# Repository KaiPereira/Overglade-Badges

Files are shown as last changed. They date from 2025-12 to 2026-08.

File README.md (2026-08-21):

# Overglade Hackathon Badges

These are zero-power hackathon badges I designed for the overglade hackathon in singapore! They're powered by the RP2040 and have passive NFC and an onboard e-ink driver! 





## Custom Features
- Passive NFC tap for whatever your heart desires
- E-ink support so that you don't need any battery
- 20 GPIO's broken out onto header pins for programming
- Active NFC mode if you want to do some more complicated stuff
- Zero power, the board needs no power for it's core features
- RP2040 SoC with 4MB flash memory
- Cool PCB and exposed copper art

## PCB Design

The PCB is a simple, 2 layer board with ground fills on each layer. I also CAD'ed the shapes and art of the board to make sure everything was perfectly symmetrical!





## Programming and Setup

The board is really easy to setup! Just plug it into your computer via USB-C, drop in the [Pi Pico micropython bootloader](https://micropython.org/download/RPI_PICO/) and then upload the [firmware](/firmware) using Thonny to the devboard! 

You can modify the `config.json` to add your own personal details, and change the images by replacing the bitmaps (I like to use [Magick](https://imagemagick.org/#gsc.tab=0) for this)!

## Ordering the PCB's

The boards are really easy to get manufactured if you'd like to have some of your own! They're much cheaper to order in bulk, at about less than $5/board and another $5 for the e-ink, but getting at MOQ will cost about $100 for 5 with PCBA (hand soldering is probably significantly cheaper though). 

I used JLC to PCBA my boards, you can just drag and drop the `gerbers.zip`, and then use the JLC BOM and designators/CPL all in the [productions folder](/PCB/production). Some of the part orientations might be off, so make sure you correct those! 

## Contributions

These were badges for the [overglade hackathon](https://overglade.hackclub.com/) in singapore, a HackClub event for highschoolers! 

Thanks to the whole overglade team for their hard work in putting the event together, and thanks to @nimitvijayvargee and @mpkendall for helping with firmware - @joysudo, @froppii and @mynameisashllee for helping with the art!

Keep on hacking o7

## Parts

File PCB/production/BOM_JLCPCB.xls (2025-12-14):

JLCPCB BOM Tool - BOM Matching
BOM name：bom-JLCPCB Assembly Order.xlsx |  |  | Download Time：2025-12-15 06:33:50 |  |  |  | * Our matching results are updated in real-time, but stock and prices may change. If it's been over 24 hours, please re-match before placing your order.
PCB Assembled Qty：5 |  |  | Est. Total Price：15.1631
Your BOM |  |  |  |  | Matched Parts |  |  |  |  |  |  | Order Information
Top Designator | Bottom Designator | Comment | Footprint | JLCPCB Part # | Matches | Part # | Manufacturer | Footprint | Description | Category | Warning | JLCPCB Part # | Product link | Lib Type | Qty | Source | Total Price ($)
C1,C2 |  | 10uF | 0805 |  | Select by System | CL21A106KAYNNNE | Samsung Electro-Mechanics | 0805 | 10uF 25V X5R ±10% 0805 Multilayer Ceramic Capacitors MLCC - SMD/SMT ROHS | Multilayer Ceramic Capacitors MLCC - SMD/SMT |  | C15850 | https://jlcpcb.com/partdetail/16532-CL21A106KAYNNNE/C15850 | Basic | 10 | 10 JLCPCB | 0.098
C10,C12,C13,C16,C29,C4,C5,C6,C7,C8,C9 |  | 0.1uF | 0402 |  | Unconfirmed | CL05B104KO5NNNC | Samsung Electro-Mechanics | 0402 | 100nF 16V X7R ±10% 0402 Multilayer Ceramic Capacitors MLCC - SMD/SMT ROHS | Multilayer Ceramic Capacitors MLCC - SMD/SMT | 1.The comment (CL05B104KO5NNNC) of this part does not match the one (0.1uF) provided in your BOM. Please confirm; | C1525 | https://jlcpcb.com/partdetail/1877-CL05B104KO5NNNC/C1525 | Basic | 55 | 55 JLCPCB | 0.066
C11,C17,C18,C19,C20,C21,C22,C23,C24,C25,C26,C3 |  | 1uF | 0402 |  | Select by System | CL05A105KA5NQNC | Samsung Electro-Mechanics | 0402 | 1uF 25V X5R ±10% 0402 Multilayer Ceramic Capacitors MLCC - SMD/SMT ROHS | Multilayer Ceramic Capacitors MLCC - SMD/SMT |  | C52923 | https://jlcpcb.com/partdetail/53938-CL05A105KA5NQNC/C52923 | Basic | 60 | 60 JLCPCB | 0.174
C14,C15,C30 |  | 33pF | 0402 |  | Select by System | 0402CG330J500NT | FH (Guangdong Fenghua Advanced Tech) | 0402 | 33pF 50V C0G ±5% 0402 Multilayer Ceramic Capacitors MLCC - SMD/SMT ROHS | Multilayer Ceramic Capacitors MLCC - SMD/SMT |  | C1562 | https://jlcpcb.com/partdetail/1914-0402CG330J500NT/C1562 | Basic | 15 | 15 JLCPCB | 0.015
C27,C28 |  | 4.7uF | 0603 |  | Select by System | CL10A475KO8NNNC | Samsung Electro-Mechanics | 0603 | 16V 4.7uF X5R ±10% 0603 Multilayer Ceramic Capacitors MLCC - SMD/SMT ROHS | Multilayer Ceramic Capacitors MLCC - SMD/SMT |  | C19666 | https://jlcpcb.com/partdetail/20375-CL10A475KO8NNNC/C19666 | Basic | 10 | 10 JLCPCB | 0.092
D1 |  | KT-0805G | 0805 |  | Select by System | KT-0805G | Hubei KENTO Elec | 0805 | -40℃~+85℃ 100mW 120° 2.6V~3.1V 430mcd 513nm~528nm 525nm 5mA Emerald Green 0805 LED Indication - Discrete ROHS | LED Indication - Discrete |  | C2297 | https://jlcpcb.com/partdetail/Hubei_KENTOElec-KT0805G/C2297 | Basic | 5 | 5 JLCPCB | 0.054
D2,D3,D4 |  | MBR0530 | D_SOD-123 |  | Select by System | MBR0530 | TWGMC | SOD-123 | 130uA 30V 5.5A 500mA 500mV@500mA Independent SOD-123 Schottky Diodes ROHS | Schottky Diodes |  | C5204746 | https://jlcpcb.com/partdetail/TWGMC-MBR0530/C5204746 | Extended | 23 | 23 JLCPCB | 0.4278
J1 |  | USB_C_Receptacle_USB2.0_16P | USB_C_Receptacle_HRO_TYPE-C-31-M-12 |  | Select by Customer | TYPE-C-31-M-12 | Korean Hroparts Elec | SMD | 1 16P 5A Female Type-C SMD USB Connectors ROHS | USB Connectors |  | C165948 | https://jlcpcb.com/partdetail/Korean_HropartsElec-TYPE_C_31_M12/C165948 | Extended | 5 | 5 JLCPCB | 0.847
L2 |  | 68uH | L_Changjiang_FNR6028S |  | Select by Customer | FNR6028S680MT | cjiang (Changjiang Microelectronics Tech) | SMD,6x6mm | 468mΩ 68uH 950mA 950mA Magnetic Shielded Inductor ±20% SMD,6x6mm Power Inductors ROHS | Power Inductors |  | C168045 | https://jlcpcb.com/partdetail/179428-FNR6028S680MT/C168045 | Extended | 6 | 6 JLCPCB | 0.3978
Q2 |  | IRLML2060 | SOT-23 |  | Unconfirmed | IRLML2060TRPBF | TECH PUBLIC | SOT-23 | 105mΩ@10V 19.5pF 247pF 2V 34pF 350mW 3A 60V 6nC@4.5V SOT-23 MOSFETs ROHS | MOSFETs | 1.The comment (IRLML2060TRPBF) of this part does not match the one (IRLML2060) provided in your BOM. Please confirm; | C5122027 | https://jlcpcb.com/partdetail/TECHPUBLIC-IRLML2060TRPBF/C5122027 | Extended | 9 | 9 JLCPCB | 0.5607
R1,R2 |  | 5.1K | 0402 |  | Unconfirmed | 0402WGF5101TCE | UNI-ROYAL(Uniroyal Elec) | 0402 | -55℃~+155℃ 5.1kΩ 50V 62.5mW Thick Film Resistor ±1% ±100ppm/℃ 0402 Chip Resistor - Surface Mount ROHS | Chip Resistor - Surface Mount | 1.The comment (0402WGF5101TCE) of this part does not match the one (5.1K) provided in your BOM. Please confirm; | C25905 | https://jlcpcb.com/partdetail/26648-0402WGF5101TCE/C25905 | Basic | 10 | 10 JLCPCB | 0.005
R3,R4 |  | 22 | 0402 |  | Unconfirmed | 0402WGF220JTCE | UNI-ROYAL(Uniroyal Elec) | 0402 | -55℃~+155℃ 22Ω 50V 62.5mW Thick Film Resistor ±1% ±100ppm/℃ 0402 Chip Resistor - Surface Mount ROHS | Chip Resistor - Surface Mount | 1.The comment (0402WGF220JTCE) of this part does not match the one (22) provided in your BOM. Please confirm; | C25092 | https://jlcpcb.com/partdetail/25835-0402WGF220JTCE/C25092 | Basic | 10 | 10 JLCPCB | 0.006
R6,R9 |  | 1K | 0402 |  | Unconfirmed | 0402WGF1001TCE | UNI-ROYAL(Uniroyal Elec) | 0402 | -55℃~+155℃ 1kΩ 50V 62.5mW Thick Film Resistor ±1% ±100ppm/℃ 0402 Chip Resistor - Surface Mount ROHS | Chip Resistor - Surface Mount | 1.The comment (0402WGF1001TCE) of this part does not match the one (1K) provided in your BOM. Please confirm; | C11702 | https://jlcpcb.com/partdetail/12256-0402WGF1001TCE/C11702 | Basic | 10 | 10 JLCPCB | 0.006
R7 |  | 220 | 0402 |  | Unconfirmed | 0402WGF2200TCE | UNI-ROYAL(Uniroyal Elec) | 0402 | -55℃~+155℃ 220Ω 50V 62.5mW Thick Film Resistor ±1% ±100ppm/℃ 0402 Chip Resistor - Surface Mount ROHS | Chip Resistor - Surface Mount | 1.The comment (0402WGF2200TCE) of this part does not match the one (220) provided in your BOM. Please confirm; | C25091 | https://jlcpcb.com/partdetail/25834-0402WGF2200TCE/C25091 | Basic | 5 | 5 JLCPCB | 0.003
R10,R11,R13,R14,R5,R8 |  | 10K | 0402 |  | Unconfirmed | 0402WGF1002TCE | UNI-ROYAL(Uniroyal Elec) | 0402 | -55℃~+155℃ 10kΩ 50V 62.5mW Thick Film Resistor ±1% ±100ppm/℃ 0402 Chip Resistor - Surface Mount ROHS | Chip Resistor - Surface Mount | 1.The comment (0402WGF1002TCE) of this part does not match the one (10K) provided in your BOM. Please confirm; | C25744 | https://jlcpcb.com/partdetail/26487-0402WGF1002TCE/C25744 | Basic | 30 | 30 JLCPCB | 0.015
R12 |  | 0.47 | 0402 |  | Unconfirmed | 0402WGF470LTCE | UNI-ROYAL(Uniroyal Elec) | 0402 | -55℃~+155℃ 470mΩ 50V 62.5mW Thick Film Resistor ±1% ±800ppm/℃ 0402 Chip Resistor - Surface Mount ROHS | Chip Resistor - Surface Mount | 1.The comment (0402WGF470LTCE) of this part does not match the one (0.47) provided in your BOM. Please confirm; | C423162 | https://jlcpcb.com/partdetail/416112-0402WGF470LTCE/C423162 | Extended | 20 | 20 JLCPCB | 0.078
SW1,SW2,SW3 |  | TSA016A2526B | SW_Push_SPST_TSA016 |  | Select by System | TSA016A2526B | BZCN | SMD,4.2x3.4mm | 12V 2.5mm 2.6N 3.35mm 4.2mm 50mA Oval Button Surface Mount,Vertical White SMD,4.2x3.4mm Tactile Switches ROHS | Tactile Switches |  | C2888429 | https://jlcpcb.com/partdetail/BZCN-TSA016A2526B/C2888429 | Extended | 20 | 20 JLCPCB | 0.418
U1 |  | RP2040 | QFN-56-1EP_7x7mm_P0.4mm_EP3.2x3.2mm |  | Select by Customer | RP2040 | Raspberry Pi | LQFN-56(7x7) | 12bit 133MHz 30 LQFN-56(7x7) Microcontrollers (MCU/MPU/SOC) ROHS | Microcontrollers (MCU/MPU/SOC) |  | C2040 | https://jlcpcb.com/partdetail/RaspberryPi-RP2040/C2040 | Extended | 5 | 5 JLCPCB | 4.5825
U2 |  | USBLC6-2SC6 | SOT-23-6 |  | Select by System | USBLC6-2SC6 | TECH PUBLIC | SOT-23-6 | -55℃~+125℃ 0.35pF 12V 150W 2 5V 6A 6V 80nA ESD IEC 61000-4-2 Unidirectional SOT-23-6 ESD and Surge Protection (TVS/ESD) ROHS | ESD And Surge Protection (TVS/ESD) |  | C2827654 | https://jlcpcb.com/partdetail/TECHPUBLIC-USBLC62SC6/C2827654 | Extended | 9 | 9 JLCPCB | 0.3348
U3 |  | NCP1117ST33T3G | SOT-223-3_TabPin2 |  | Select by System | NCP1117ST33T3G | onsemi | SOT-223 | 0.003%Vout 0℃~+125℃@(Ta) 1 1.2V@(800mA) 1A 20V 3.3V 62dB@(120Hz) 6mA Fixed Over Current Protection Positive SOT-223 Voltage Regulators - Linear, Low Drop Out (LDO) Regulators ROHS | Voltage Regulators - Linear, Low Drop Out (LDO) Regulators |  | C26537 | https://jlcpcb.com/partdetail/onsemi-NCP1117ST33T3G/C26537 | Extended | 5 | 5 JLCPCB | 1.119
U4 |  | W25Q32JVSS | SOIC-8_5.3x5.3mm_P1.27mm |  | Unconfirmed | W25Q32JVSSIQ | Winbond Elec | SOIC-8-208mil | -40℃~+85℃ 100,000 Cycles 133MHz 1uA 2.7V~3.6V 20 Years 32Mbit 3ms SPI SOIC-8-208mil NOR FLASH ROHS | NOR FLASH | 1.The comment (W25Q32JVSSIQ) of this part does not match the one (W25Q32JVSS) provided in your BOM. Please confirm; | C179173 | https://jlcpcb.com/partdetail/WinbondElec-W25Q32JVSSIQ/C179173 | Extended | 5 | 5 JLCPCB | 3.2475
U5 |  | Conn | LCSC_1x24-1MP_P0.5mm_Horizontal |  | Select by System | AFC07-S24FCA-00 | JUSHUO | SMD,P=0.5mm,卧贴 | 0.3mm 0.5mm 24P 2mm Bottom Contact Copper Alloy Slide Lock Surface Mount, Right Angle Tin SMD,P=0.5mm,Surface Mount，Right Angle FFC, FPC (Flat Flexible) Connector Assemblies ROHS | FFC, FPC (Flat Flexible) Connector Assemblies |  | C262567 | https://jlcpcb.com/partdetail/JUSHUO-AFC07_S24FCA00/C262567 | Extended | 5 | 5 JLCPCB | 0.5985
U6 |  | ST25DV04K-JFR6D3 | ST_UFDFPN-12-1EP_3x3mm_P0.5mm_EP1.4x2.55mm |  | Select by System | ST25DV04K-JFR6D3 | STMicroelectronics | UDFN-12-EP(3x3) | 1.8V~5.5V 53Kbit/s I2C ISO 15693,NFC UDFN-12-EP(3x3) RFID ICs ROHS | RFID ICs |  | C2654815 | https://jlcpcb.com/partdetail/STMicroelectronics-ST25DV04KJFR6D3/C2654815 | Extended | 5 | 5 JLCPCB | 1.695
Y1 |  | 12MHz | Crystal_SMD_3225-4Pin_3.2x2.5mm |  | Select by Customer | X322512MSB4SI | YXC Crystal Oscillators | SMD3225-4P | -40℃~+85℃ 12MHz 20pF Crystal Oscillator ±10ppm ±20ppm SMD3225-4P Crystals ROHS | Crystals |  | C9002 | https://jlcpcb.com/partdetail/YXC_CrystalOscillators-X322512MSB4SI/C9002 | Basic | 5 | 5 JLCPCB | 0.3225
J2,J3 |  | Conn_01x15 | PinHeader_PAD_1x15_P2.54mm_Vertical |  | No matches | No Part Selected
L1 |  | NFCAntenna | 25x35mm-NFC |  | No matches | No Part Selected

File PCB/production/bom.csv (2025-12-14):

Designator | Footprint | Quantity | Value | LCSC Part #
C1, C2 | 0805 | 2 | 10uF
C10, C12, C13, C16, C29, C4, C5, C6, C7, C8, C9 | 0402 | 11 | 0.1uF
C11, C17, C18, C19, C20, C21, C22, C23, C24, C25, C26, C3 | 0402 | 12 | 1uF
C14, C15, C30 | 0402 | 3 | 33pF
C27, C28 | 0603 | 2 | 4.7uF
D1 | 0805 | 1 | KT-0805G
D2, D3, D4 | D_SOD-123 | 3 | MBR0530
J1 | USB_C_Receptacle_HRO_TYPE-C-31-M-12 | 1 | USB_C_Receptacle_USB2.0_16P
J2, J3 | PinHeader_PAD_1x15_P2.54mm_Vertical | 2 | Conn_01x15
L1 | 25x35mm-NFC | 1 | NFC Antenna
L2 | L_Changjiang_FNR6028S | 1 | 68uH | FNR6028S680MT
Q2 | SOT-23 | 1 | IRLML2060
R1, R2 | 0402 | 2 | 5.1K
R10, R11, R13, R14, R5, R8 | 0402 | 6 | 10K
R12 | 0402 | 1 | 0.47
R3, R4 | 0402 | 2 | 22
R6, R9 | 0402 | 2 | 1K
R7 | 0402 | 1 | 220
SW1, SW2, SW3 | SW_Push_SPST_TSA016 | 3 | TSA016A2526B
U1 | QFN-56-1EP_7x7mm_P0.4mm_EP3.2x3.2mm | 1 | RP2040
U2 | SOT-23-6 | 1 | USBLC6-2SC6
U3 | SOT-223-3_TabPin2 | 1 | NCP1117ST33T3G
U4 | SOIC-8_5.3x5.3mm_P1.27mm | 1 | W25Q32JVSS
U5 | LCSC_1x24-1MP_P0.5mm_Horizontal | 1 | Conn | C262567
U6 | ST_UFDFPN-12-1EP_3x3mm_P0.5mm_EP1.4x2.55mm | 1 | ST25DV04K-JFR6D3
Y1 | Crystal_SMD_3225-4Pin_3.2x2.5mm | 1 | 12MHz | X322512MSB4SI

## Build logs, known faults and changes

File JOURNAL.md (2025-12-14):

---
title: Overglade PCB's
author: Kai Pereira
description: NFC hackathon badges for the Overglade game jam in Singapore!
created_at: 2025-12-14
hours: "35"
---
## Let's get into it

This is a retroactive journal of how I made the Overglade PCB's, I absolutely locked in and made these really quick, so I didn't want the overhead of actively journaling it.

The first part of the PCB is the power.

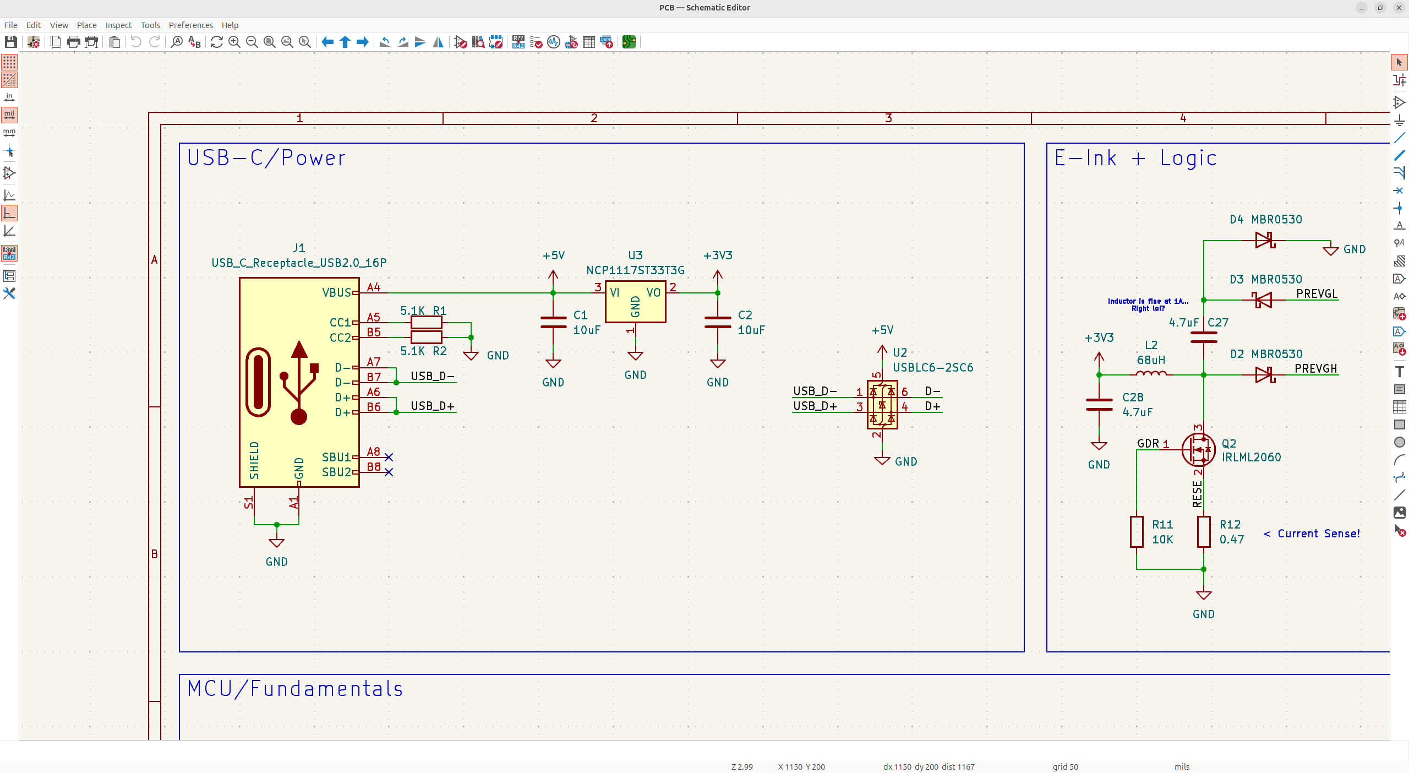
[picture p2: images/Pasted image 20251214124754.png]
Pasted image 20251214124754.png


I decided to use USB-C because it's the most common cable these days and has really good power, and data. I use the NCP1117 fixed LDO to power 3V3 because it's very good, and can step down 1A which is the max draw of my board.

I added ESD protection because lots of people are writing and messing with their badges, so I don't want to accidentally fry the PCB.

The next part of the PCB is the MCU. I decided on RP2040, because it's insanely easy to program, cheap and is just really fast to get working!

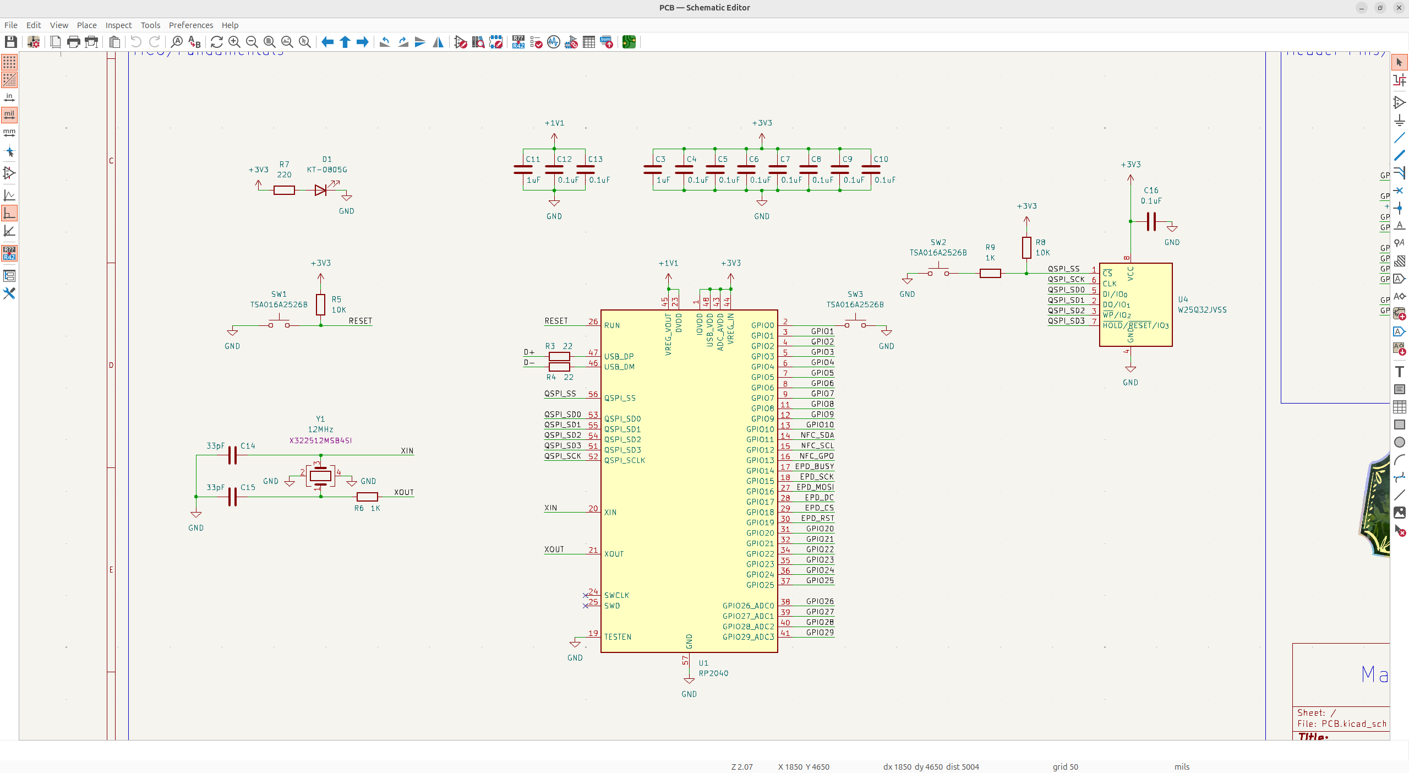
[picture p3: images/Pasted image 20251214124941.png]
Pasted image 20251214124941.png


This is a really simple RP2040 implementation. It's just one cap per VDD pin, and then a bulk cap for each line.

I added a power LED to show that power is actually getting to the board, and a BOOT and RESET button for programming. There's an external crystal for the USB-C timing, and then I strategically wired the GPIO's for the easiest routing to the pin headers.

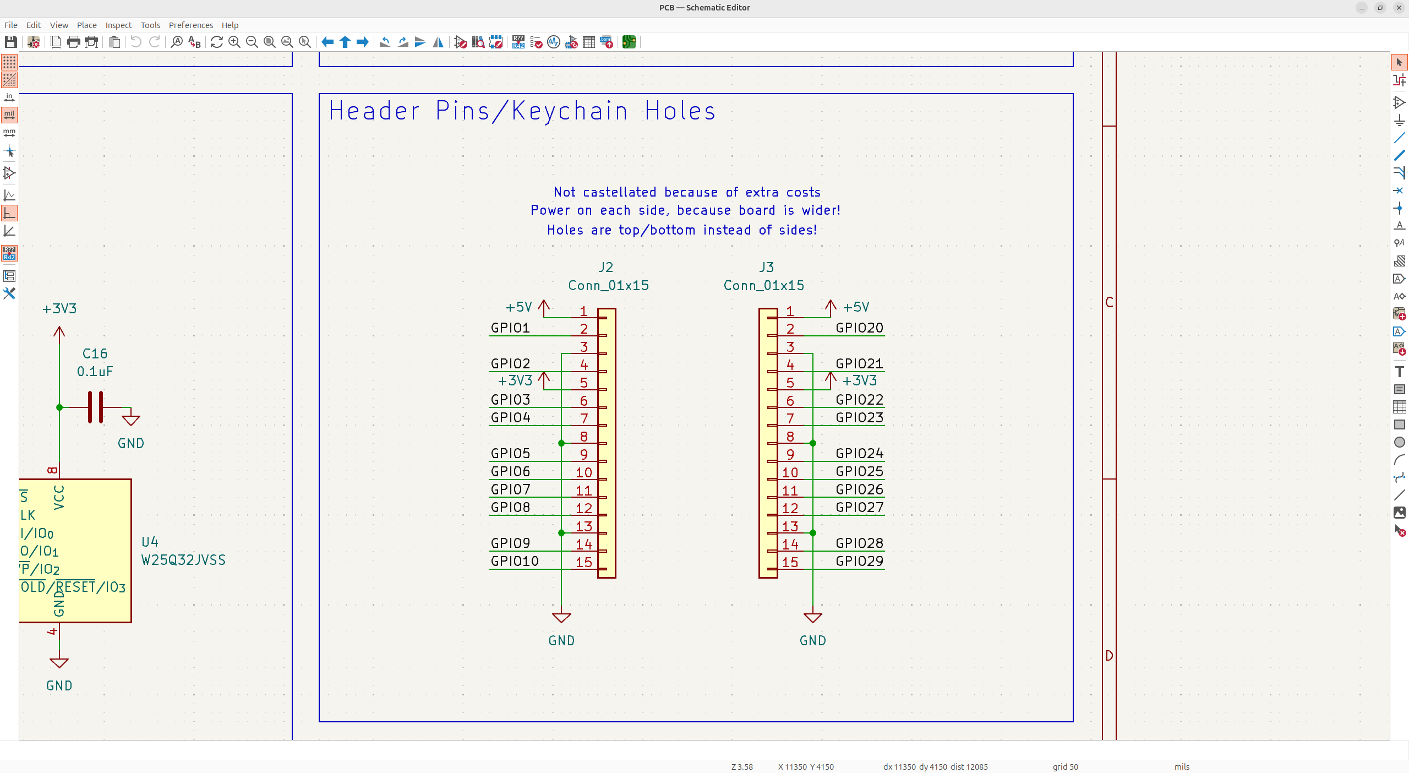
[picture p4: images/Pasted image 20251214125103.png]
Pasted image 20251214125103.png


The pin headers is near standard with the RP2040, but it is smaller. I didn't put too much thought into it, but just wanted to break out everything to be accessible and useful to the user.

Next, I needed to have an e-ink on the board.

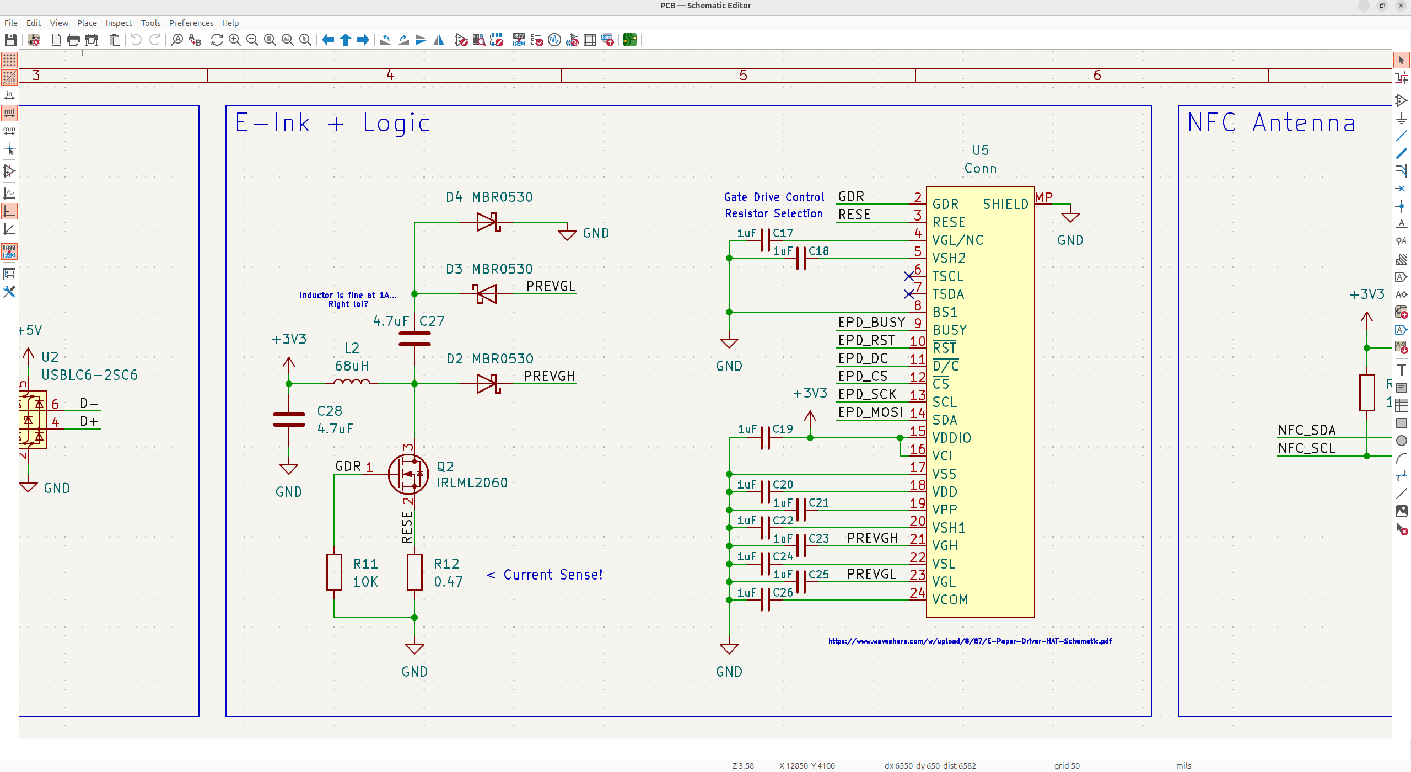
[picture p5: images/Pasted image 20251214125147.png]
Pasted image 20251214125147.png

This PCB should work with absolutely no power, so that's why I decided on an e-ink because it's a passive display and doesn't actively need power. I copied the waveshare reference schematic for this part, but I understand the e-ink at a fair level.

There's decoupling on all the lines that are driving power to the e-ink:
- Pre-VGH is the previous high voltage which is important to move the charged particles in the e-ink
- Pre-VGL is the previous gate low which is also a key aspect of moving the particles, and these 2 together are basically moving in sync to make the particles move quickly and efficiently. 

It's driven by SPI, and has resistor selection for different displays, and also a gate drive control which drives it on and off to actively change the display.

There's an inductor to help with the internal DC-DC boost converter inside of the e-ink and decoupling for it too.

Finally, we have the NFC tag:

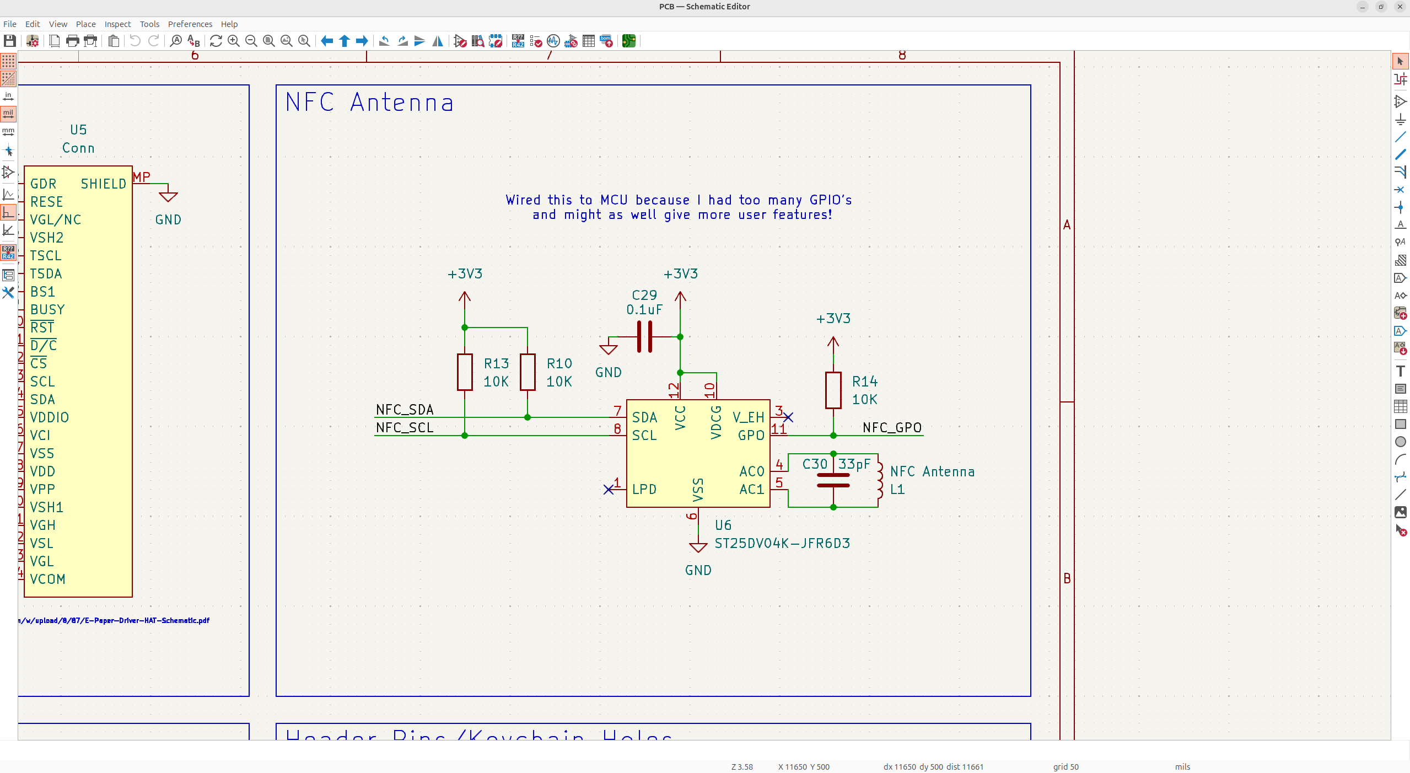
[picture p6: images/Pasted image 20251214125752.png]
Pasted image 20251214125752.png


The IC is called the tag, and then the inductor symbol is where the antenna is. It works passively by harvesting the energy from the magnetic fields on your phone, but I decided to also implement active NFC so I wired the I2C and the other control pins so that people can customize it even further.

You'll notice the load cap on the antenna, this is the same one as the crystal to minimize the BOM, and it's for frequency tuning, so it smooths the capacitance of the antenna for impedance matching. 

And just like that, we have our entire schematic!

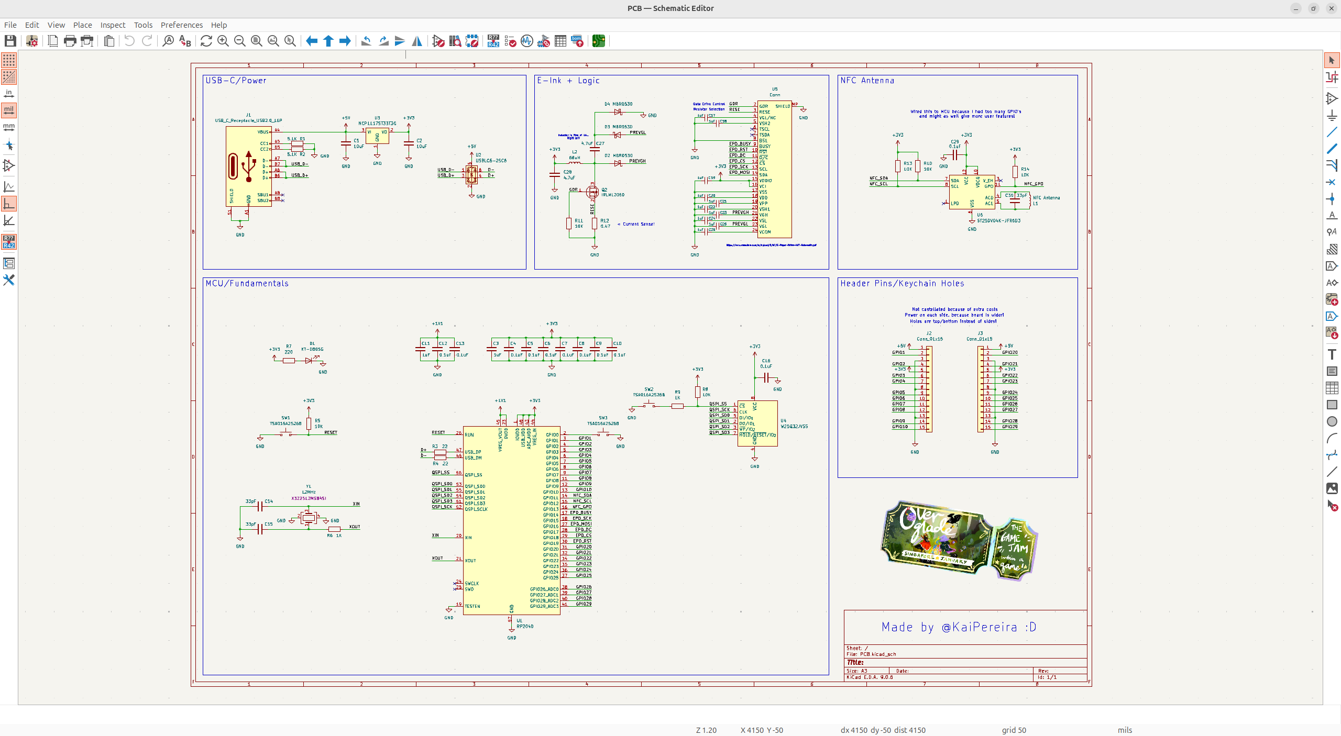
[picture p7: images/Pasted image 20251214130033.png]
Pasted image 20251214130033.png


Now, let's get onto the PCB!

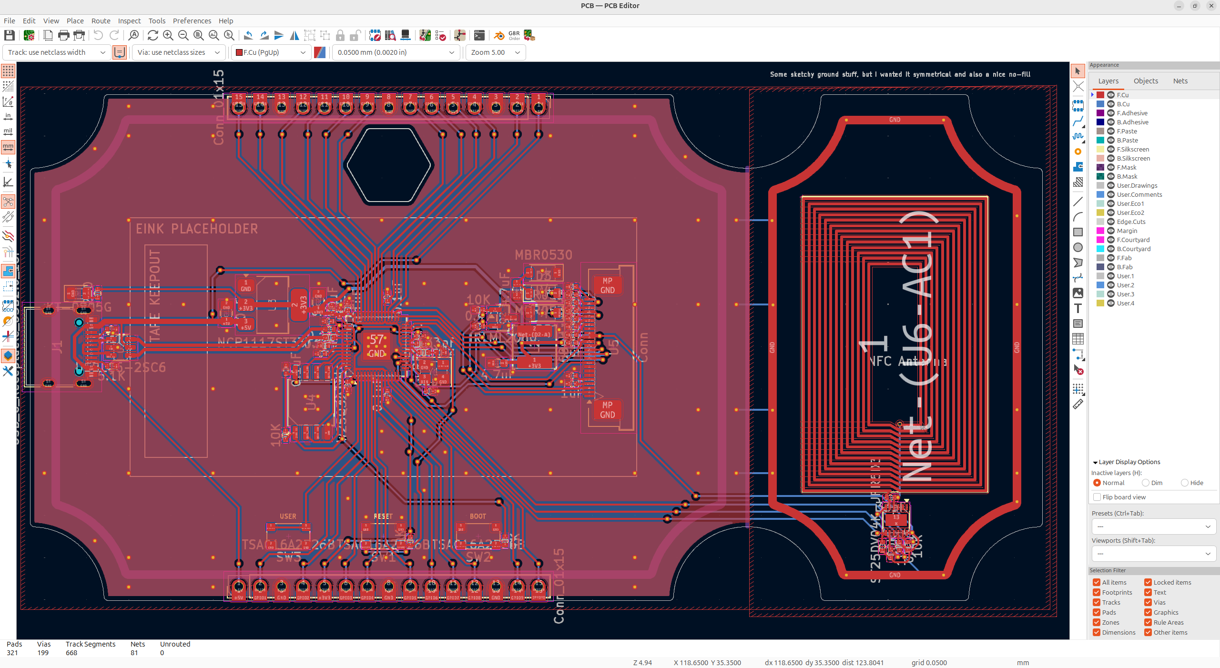
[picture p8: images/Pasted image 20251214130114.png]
Pasted image 20251214130114.png


I'll just give a brief overview of the main logic, but essentially, it's in the shape of a ticket, which was a sticker I liked that Kai Ling made, so I wanted to follow that idea because I think it would be really cool.

The power traces are thick enough to drive 1A, and then USB is 90 ohm impedance matched. My routing probably could've been more clean, but it's fine for a quick board. 

The hole is very specific, and I designed it that way because the board will be right side heavy, so I wanted the clip to help balance that out, by hitting the angle of the hexagon and not sliding.

Next, let's talk about the NFC antenna. I used https://eds.st.com/antenna/#/ to generate an optimal antenna, which needed to be a target inductance of 4.7uH. I then used https://github.com/nideri/nfc_antenna_generator to create the actual footprint, and then I added my own via's to it, and I also decided on using an angled center to the NFC tag, so that I could put the IC directly centered under the antenna.

Finally, we have some of the cosmetic aspects of the PCB. I added exposed copper art by having soldermask designs around the PCB, and then the ground fill would go over that and make it look at coppery. Pretty fancy :D 

There's no ground fill under the NFC antenna, because I don't want it to dampen the antenna, and I am a bit worried because there's one surrounding it, but I think I'm just overthinking it. I also made a custom header footprint because I thought it looked really cool! 

And just like that, that's our PCB finished! 

I then generated all the production files using the KiCad fabrication toolkit plugin, and it's ready for JLC! There's a lot of stuff I didn't mention, but that's a general overview of the PCB!

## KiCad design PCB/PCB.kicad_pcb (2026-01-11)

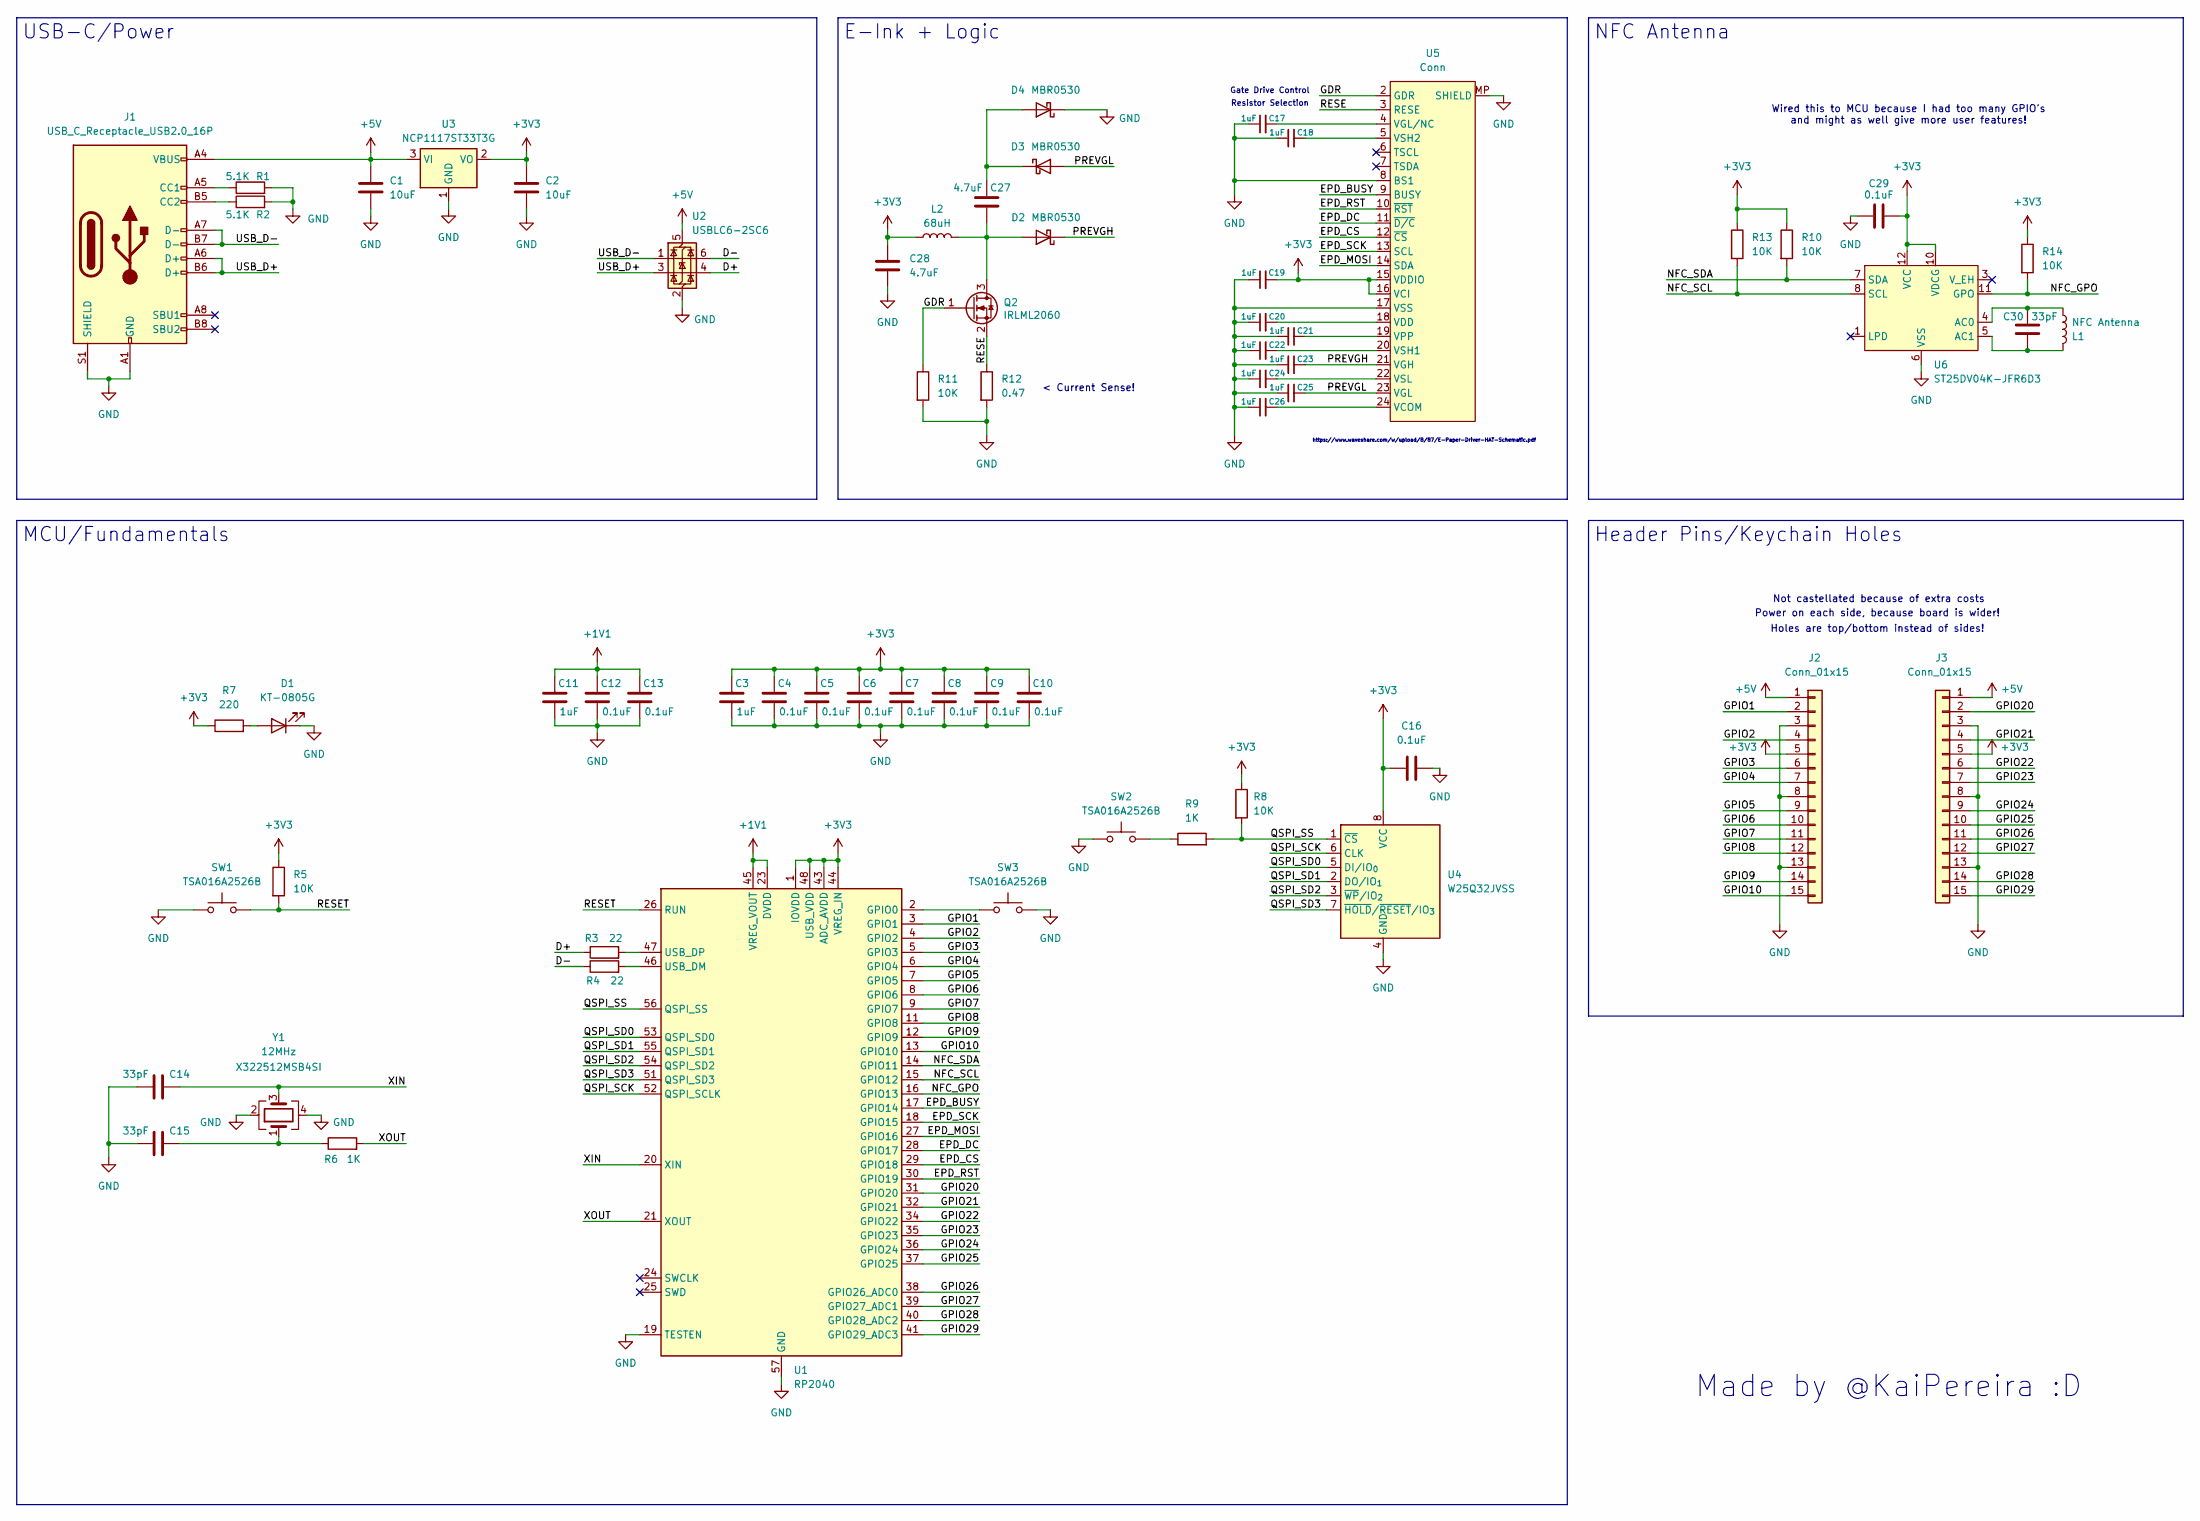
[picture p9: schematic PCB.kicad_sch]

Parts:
C1, C2: 10uF; C_0805_2012Metric
C3, C11, C17, C18, C19, C20, C21, C22, C23, C24, C25, C26: 1uF; C_0402_1005Metric
C4, C5, C6, C7, C8, C9, C10, C12, C13, C16, C29: 0.1uF; C_0402_1005Metric
C14, C15, C30: 33pF; C_0402_1005Metric
C27, C28: 4.7uF; C_0603_1608Metric
D1: KT-0805G; LED_0805_2012Metric
D2, D3, D4: MBR0530; D_SOD-123
J1: USB_C_Receptacle_USB2.0_16P; USB_C_Receptacle_HRO_TYPE-C-31-M-12
J2, J3: Conn_01x15; PinHeader_PAD_1x15_P2.54mm_Vertical
L1: NFC Antenna; 25x35mm-NFC
L2: 68uH; L_Changjiang_FNR6028S; MPN FNR6028S680MT
Q2: IRLML2060; SOT-23
R1, R2: 5.1K; R_0402_1005Metric
R3, R4: 22; R_0402_1005Metric
R5, R8, R10, R11, R13, R14: 10K; R_0402_1005Metric
R6, R9: 1K; R_0402_1005Metric
R7: 220; R_0402_1005Metric
R12: 0.47; R_0402_1005Metric
SW1, SW2, SW3: TSA016A2526B; SW_Push_SPST_TSA016
U1: RP2040; QFN-56-1EP_7x7mm_P0.4mm_EP3.2x3.2mm
U2: USBLC6-2SC6; SOT-23-6
U3: NCP1117ST33T3G; SOT-223-3_TabPin2
U4: W25Q32JVSS; SOIC-8_5.3x5.3mm_P1.27mm
U5: Conn; LCSC_1x24-1MP_P0.5mm_Horizontal; LCSC Part # C262567
U6: ST25DV04K-JFR6D3; ST_UFDFPN-12-1EP_3x3mm_P0.5mm_EP1.4x2.55mm
Y1: 12MHz; Crystal_SMD_3225-4Pin_3.2x2.5mm; MPN X322512MSB4SI

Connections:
+1V1: C11.1, C12.1, C13.1, U1.23 (DVDD), U1.45 (VREG_VOUT), U1.50 (DVDD)
+3V3: C2.1, C3.1, C4.1, C5.1, C6.1, C7.1, C8.1, C9.1, C10.1, C16.1, C19.2, C28.2, C29.2, J2.5, J3.5, L2.1, R5.1, R7.1, R8.1, R10.1, R13.1, R14.1, U1.1 (IOVDD), U1.10 (IOVDD), U1.22 (IOVDD), U1.33 (IOVDD), U1.42 (IOVDD), U1.43 (ADC_AVDD), U1.44 (VREG_IN), U1.48 (USB_VDD), U1.49 (IOVDD), U3.2 (VO), U4.8 (VCC), U5.15 (VDDIO), U5.16 (VCI), U6.10 (VDCG), U6.12 (VCC)
+5V: C1.1, J1.A4 (VBUS), J1.A9 (VBUS), J1.B4 (VBUS), J1.B9 (VBUS), J2.1, J3.1, U2.5 (VBUS), U3.3 (VI)
/D+: R3.1, U2.4 (I/O2)
/D-: R4.1, U2.6 (I/O1)
/EPD_BUSY: U1.17 (GPIO14), U5.9 (BUSY)
/EPD_CS: U1.29 (GPIO18), U5.12 (~CS)
/EPD_DC: U1.28 (GPIO17), U5.11 (~D/C)
/EPD_MOSI: U1.27 (GPIO16), U5.14 (SDA)
/EPD_RST: U1.30 (GPIO19), U5.10 (~RST)
/EPD_SCK: U1.18 (GPIO15), U5.13 (SCL)
/GDR: Q2.1 (G), R11.1, U5.2 (GDR)
/GPIO1: J2.2, U1.3 (GPIO1)
/GPIO2: J2.4, U1.4 (GPIO2)
/GPIO3: J2.6, U1.5 (GPIO3)
/GPIO4: J2.7, U1.6 (GPIO4)
/GPIO5: J2.9, U1.7 (GPIO5)
/GPIO6: J2.10, U1.8 (GPIO6)
/GPIO7: J2.11, U1.9 (GPIO7)
/GPIO8: J2.12, U1.11 (GPIO8)
/GPIO9: J2.14, U1.12 (GPIO9)
/GPIO10: J2.15, U1.13 (GPIO10)
/GPIO20: J3.2, U1.31 (GPIO20)
/GPIO21: J3.4, U1.32 (GPIO21)
/GPIO22: J3.6, U1.34 (GPIO22)
/GPIO23: J3.7, U1.35 (GPIO23)
/GPIO24: J3.9, U1.36 (GPIO24)
/GPIO25: J3.10, U1.37 (GPIO25)
/GPIO26: J3.11, U1.38 (GPIO26_ADC0)
/GPIO27: J3.12, U1.39 (GPIO27_ADC1)
/GPIO28: J3.14, U1.40 (GPIO28_ADC2)
/GPIO29: J3.15, U1.41 (GPIO29_ADC3)
/NFC_GPO: R14.2, U1.16 (GPIO13), U6.11 (GPO)
/NFC_SCL: R13.2, U1.15 (GPIO12), U6.8 (SCL)
/NFC_SDA: R10.2, U1.14 (GPIO11), U6.7 (SDA)
/PREVGH: C23.2, D2.1 (K), U5.21 (VGH)
/PREVGL: C25.2, D3.2 (A), U5.23 (VGL)
/QSPI_SCK: U1.52 (QSPI_SCLK), U4.6 (CLK)
/QSPI_SD0: U1.53 (QSPI_SD0), U4.5 (DI/IO_{0})
/QSPI_SD1: U1.55 (QSPI_SD1), U4.2 (DO/IO_{1})
/QSPI_SD2: U1.54 (QSPI_SD2), U4.3 (~WP/IO_{2})
/QSPI_SD3: U1.51 (QSPI_SD3), U4.7 (~HOLD/~RESET/IO_{3})
/QSPI_SS: R8.2, R9.2, U1.56 (QSPI_SS), U4.1 (~CS)
/RESE: Q2.2 (S), R12.1, U5.3 (RESE)
/RESET: R5.2, SW1.2, U1.26 (RUN)
/USB_D+: J1.A6 (D+), J1.B6 (D+), U2.3 (I/O2)
/USB_D-: J1.A7 (D-), J1.B7 (D-), U2.1 (I/O1)
/XIN: C14.2, U1.20 (XIN), Y1.3
/XOUT: R6.2, U1.21 (XOUT)
GND: C1.2, C2.2, C3.2, C4.2, C5.2, C6.2, C7.2, C8.2, C9.2, C10.2, C11.2, C12.2, C13.2, C14.1, C15.1, C16.2, C17.1, C18.1, C19.1, C20.1, C21.1, C22.1, C23.1, C24.1, C25.1, C26.1, C28.1, C29.1, D1.1 (K), D4.1 (K), J1.A1 (GND), J1.A12 (GND), J1.B1 (GND), J1.B12 (GND), J1.S1 (SHIELD), J2.3, J2.8, J2.13, J3.3, J3.8, J3.13, R1.2, R2.2, R11.2, R12.2, SW1.1, SW2.1, SW3.2, U1.19 (TESTEN), U1.57 (GND), U2.2 (GND), U3.1 (GND), U4.4 (GND), U5.8 (BS1), U5.17 (VSS), U5.MP (SHIELD), U6.6 (VSS), Y1.2, Y1.4
unnamed: C15.2, R6.1, Y1.1
unnamed: D1.2 (A), R7.2
unnamed: C27.2, D2.2 (A), L2.2, Q2.3 (D)
unnamed: C27.1, D3.1 (K), D4.2 (A)
unnamed: J1.A5 (CC1), R1.1
unnamed: J1.B5 (CC2), R2.1
unnamed: R9.1, SW2.2
unnamed: SW3.1, U1.2 (GPIO0)
unnamed: R4.2, U1.46 (USB_DM)
unnamed: R3.2, U1.47 (USB_DP)
unnamed: C26.2, U5.24 (VCOM)
unnamed: C20.2, U5.18 (VDD)
unnamed: C17.2, U5.4 (VGL/NC)
unnamed: C21.2, U5.19 (VPP)
unnamed: C22.2, U5.20 (VSH1)
unnamed: C18.2, U5.5 (VSH2)
unnamed: C24.2, U5.22 (VSL)
unnamed: C30.2, L1.2, U6.4 (AC0)
unnamed: C30.1, L1.1, U6.5 (AC1)

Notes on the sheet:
https://www.waveshare.com/w/upload/8/87/E-Paper-Driver-HAT-Schematic.pdf
Made by @KaiPereira :D
Power on each side, because board is wider!
Resistor Selection
Wired this to MCU because I had too many GPIO's and might as well give more user features!
Gate Drive Control
< Current Sense!
Holes are top/bottom instead of sides!
Not castellated because of extra costs
E-Ink + Logic
MCU/Fundamentals
USB-C/Power
Header Pins/Keychain Holes
NFC Antenna

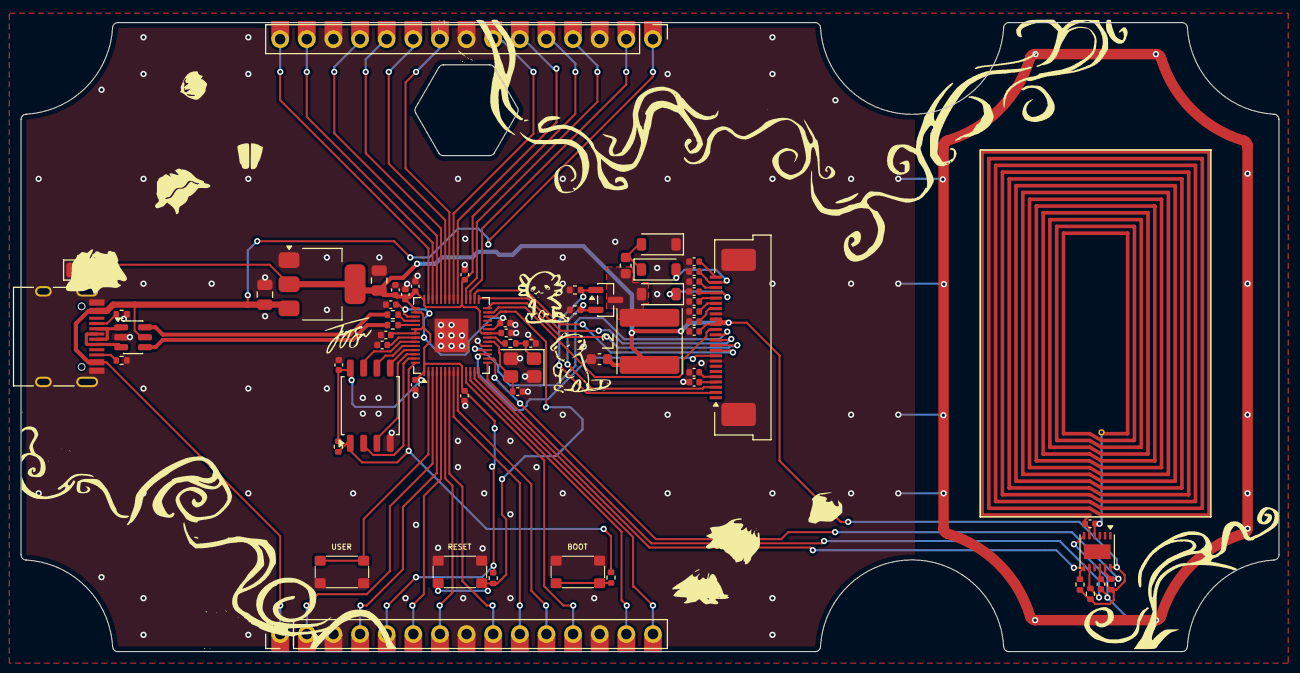
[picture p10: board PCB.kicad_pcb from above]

Board: 2 copper layers, 120.0 x 60.0 mm, 64 parts (0 on the bottom side), 69 nets.

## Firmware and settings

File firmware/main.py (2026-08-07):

from machine import Pin, SoftSPI, PWM, unique_id
import utime
import framebuf
import struct

# The pins selected on the microcontroller on the badges are not default SPI pins.
spi = SoftSPI(
    baudrate=1_000_000,
    polarity=0,
    phase=0,
    sck=Pin(15),
    mosi=Pin(16),
    miso=Pin(20),
)

# Data is fetched from the config.json file, use the badge tool to upload a file.

badge_data = {
    "name": None,
    "pronouns": None,
    "slack_handle": None,
    "scale": None,
    "party_number": None,
}
# Is Staff configures the badge to show "Staff" since staff were not part of a party during the event.
is_staff = False
configured = False
try:
    with open("config.json", "r") as f:
        import json

        config = json.load(f)
        badge_data["name"] = config.get("userName")
        badge_data["pronouns"] = config.get("userPronouns")
        badge_data["slack_handle"] = config.get("userHandle")
        badge_data["party_number"] = config.get("partyNumber")
        badge_data["scale"] = config.get("nameScale")
        is_staff = config.get("isStaff")
        configured = all(v is not None for v in badge_data.values())
except Exception as e:
    print("Config error:", e)
    configured = False


"""
File conversion helper to write a bitmap into the display. 
This only supports bitmaps of 1b depth.
Use Magick or similar tool to construct a valid bitmap.
"""

def bmp_to_framebuf_at(path, fb, x0, y0, max_w=80, max_h=80):
    with open(path, "rb") as f:
        if f.read(2) != b"BM":
            raise ValueError("Not a BMP")

        f.seek(10)
        data_offset = struct.unpack("<I", f.read(4))[0]

        f.seek(18)
        w, h = struct.unpack("<ii", f.read(8))
        h = abs(h)

        f.seek(28)
        bpp = struct.unpack("<H", f.read(2))[0]
        if bpp not in (1, 24):
            raise ValueError("Unsupported BMP depth")

        f.seek(data_offset)
        row_bytes = ((w * bpp + 31) // 32) * 4

        draw_w = min(w, max_w)
        draw_h = min(h, max_h)

        for y in range(draw_h):
            row = f.read(row_bytes)
            py = h - 1 - y  # BMP bottom-up

            for x in range(draw_w):
                if bpp == 1:
                    bit = row[x >> 3] & (0x80 >> (x & 7))
                    color = 0 if bit else 1
                else:
                    b, g, r = row[x * 3 : x * 3 + 3]
                    color = 0 if (r + g + b) > 384 else 1

                fb.pixel(x0 + x, y0 + py, color)


# Configure misc display (non-SPI)
from einkdriver import EPD

disp_cs = Pin(18, Pin.OUT)
disp_dc = Pin(17, Pin.OUT)
disp_rst = Pin(19, Pin.OUT)
disp_busy = Pin(14, Pin.IN)

epd = EPD()

# Main Render code
epd.image_Landscape.fill(0xFF)
# Thanks froppii for the overglade.bmp design :)
bmp_to_framebuf_at("overglade.bmp", epd.image_Landscape, 0, 0, 296, 152)
# image.bmp (80x80), loaded via badge tool into the badge. Must be 1b depth.
bmp_to_framebuf_at("image.bmp", epd.image_Landscape, 15, 25, 80, 80)

if configured:
    epd.image_Landscape.rect(10, 20, 90, 90, 0x00)
    epd.text_scaled(badge_data["name"], 105, 40, badge_data["scale"], 0x00)
    if not is_staff:
        epd.text_scaled("Party " + str(badge_data["party_number"]), 105, 64, 2, 0x00)
    else:
        epd.text_scaled("Staff", 105, 64, 2, 0x00)

    epd.text_scaled("(" + badge_data["pronouns"] + ")", 105, 112, 1, 0x00)
    epd.text_scaled("@" + badge_data["slack_handle"], 105, 120, 1, 0x00)

# Fallback
else:
    epd.text_scaled("Configuration", 10, 13, 2, 0x00)
    epd.text_scaled("Missing", 10, 32, 2, 0x00)

epd.display_Landscape(epd.buffer_Landscape)

# die
utime.sleep_ms(2000)
epd.init(0)
utime.sleep_ms(2000)
epd.sleep()

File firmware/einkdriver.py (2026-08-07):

from machine import Pin, SoftSPI 
import framebuf
import utime

# Display resolution
EPD_WIDTH       = 152
EPD_HEIGHT      = 296

RST_PIN         = 19
DC_PIN          = 17
CS_PIN          = 18
BUSY_PIN        = 14


WF_PARTIAL_2IN66 =[
0x00,0x40,0x00,0x00,0x00,0x00,0x00,0x00,0x00,0x00,
0x00,0x00,0x80,0x80,0x00,0x00,0x00,0x00,0x00,0x00,
0x00,0x00,0x00,0x00,0x40,0x40,0x00,0x00,0x00,0x00,
0x00,0x00,0x00,0x00,0x00,0x00,0x00,0x80,0x00,0x00,
0x00,0x00,0x00,0x00,0x00,0x00,0x00,0x00,0x00,0x00,
0x00,0x00,0x00,0x00,0x00,0x00,0x00,0x00,0x00,0x00,
0x0A,0x00,0x00,0x00,0x00,0x00,0x02,0x01,0x00,0x00,
0x00,0x00,0x00,0x00,0x01,0x00,0x00,0x00,0x00,0x00,
0x00,0x00,0x00,0x00,0x00,0x00,0x00,0x00,0x00,0x00,
0x00,0x00,0x00,0x00,0x00,0x00,0x00,0x00,0x00,0x00,
0x00,0x00,0x00,0x00,0x00,0x00,0x00,0x00,0x00,0x00,
0x00,0x00,0x00,0x00,0x00,0x00,0x00,0x00,0x00,0x00,
0x00,0x00,0x00,0x00,0x00,0x00,0x00,0x00,0x00,0x00,
0x00,0x00,0x00,0x00,0x00,0x00,0x00,0x00,0x00,0x00,
0x00,0x00,0x00,0x00,0x22,0x22,0x22,0x22,0x22,0x22,
0x00,0x00,0x00,0x22,0x17,0x41,0xB0,0x32,0x36,
]

class EPD:
    def __init__(self):
        self.reset_pin = Pin(RST_PIN, Pin.OUT)
        self.busy_pin = Pin(BUSY_PIN, Pin.IN, Pin.PULL_UP)
        self.cs_pin = Pin(CS_PIN, Pin.OUT)
        self.width = EPD_WIDTH
        self.height = EPD_HEIGHT
        self.lut = WF_PARTIAL_2IN66

        self.spi = SoftSPI(baudrate=1_000_000, polarity=0, phase=0, sck=Pin(15), mosi=Pin(16), miso=Pin(20))
        self.dc_pin = Pin(DC_PIN, Pin.OUT)
        
        self.buffer_Landscape = bytearray(self.height * self.width // 8)
        self.buffer_Portrait = bytearray(self.height * self.width // 8)
        
        self.image_Landscape = framebuf.FrameBuffer(self.buffer_Landscape, self.height, self.width, framebuf.MONO_VLSB)
        self.image_Portrait = framebuf.FrameBuffer(self.buffer_Portrait, self.width, self.height, framebuf.MONO_HLSB)
        self.init(0)

    # Hardware reset
    def reset(self):
        self.reset_pin(1)
        utime.sleep_ms(200) 
        self.reset_pin(0)
        utime.sleep_ms(200)
        self.reset_pin(1)
        utime.sleep_ms(200)   

    def send_command(self, command):
        self.cs_pin(1)
        self.dc_pin(0)
        self.cs_pin(0)
        self.spi.write(bytearray([command]))
        self.cs_pin(1)

    def send_data(self, data):
        self.cs_pin(1)
        self.dc_pin(1)
        self.cs_pin(0)
        self.spi.write(bytearray([data]))
        self.cs_pin(1)
        
    def send_data1(self, buf):
        self.cs_pin(1)
        self.dc_pin(1)
        self.cs_pin(0)
        self.spi.write(bytearray(buf))
        self.cs_pin(1)
        
    def ReadBusy(self):
        print('e-Paper busy')
        utime.sleep_ms(100)   
        while(self.busy_pin.value() == 1):      # 0: idle, 1: busy
            utime.sleep_ms(100)    
        print('e-Paper busy release')
        utime.sleep_ms(100)  
        
    def TurnOnDisplay(self):
        self.send_command(0x20)        
        self.ReadBusy()
        
    def SendLut(self):
        self.send_command(0x32)
        for i in range(0, 153):
            self.send_data(self.lut[i])
        self.ReadBusy()
    
    def SetWindow(self, x_start, y_start, x_end, y_end):
        self.send_command(0x44) # SET_RAM_X_ADDRESS_START_END_POSITION
        # x point must be the multiple of 8 or the last 3 bits will be ignored
        self.send_data((x_start>>3) & 0xFF)
        self.send_data((x_end>>3) & 0xFF)
        self.send_command(0x45) # SET_RAM_Y_ADDRESS_START_END_POSITION
        self.send_data(y_start & 0xFF)
        self.send_data((y_start >> 8) & 0xFF)
        self.send_data(y_end & 0xFF)
        self.send_data((y_end >> 8) & 0xFF)

    def SetCursor(self, x, y):
        self.send_command(0x4E) # SET_RAM_X_ADDRESS_COUNTER
        self.send_data(x & 0xFF)
        
        self.send_command(0x4F) # SET_RAM_Y_ADDRESS_COUNTER
        self.send_data(y & 0xFF)
        self.send_data((y >> 8) & 0xFF)
    
    def init(self, mode):
        
        self.reset()
         
        self.send_command(0x12)  #SWRESET
        self.ReadBusy()
        
        self.send_command(0x11)
        self.send_data(0x03)
        
        self.SetWindow(8, 0, self.width, self.height)
   
        if(mode == 0):
            self.send_command(0x3c)
            self.send_data(0x01)
        elif(mode == 1):
            self.SendLut()
            self.send_command(0x37) # set display option, these setting turn on previous function
            self.send_data(0x00)
            self.send_data(0x00)
            self.send_data(0x00)
            self.send_data(0x00)
            self.send_data(0x00)  
            self.send_data(0x40)
            self.send_data(0x00)
            self.send_data(0x00)
            self.send_data(0x00)
            self.send_data(0x00)

            self.send_command(0x3C)
            self.send_data(0x80)

            self.send_command(0x22)
            self.send_data(0xcf)
            
            self.send_command(0x20)
            self.ReadBusy()
            
        else: 
            print("There is no such mode")
    
    def display(self, image):
        if (image == None):
            return            
            
        self.SetCursor(1, 295)
        
        self.send_command(0x24) # WRITE_RAM
        self.send_data1(image)
        self.TurnOnDisplay()
        
    def display_Landscape(self, image):
        if(self.width % 8 == 0):
            Width = self.width // 8
        else:
            Width = self.width // 8 +1
        Height = self.height
        
        self.SetCursor(1, 295)
        
        self.send_command(0x24)
        for j in range(Height):
            for i in range(Width):
                self.send_data(image[(Width-i-1) * Height + j])
                
        self.TurnOnDisplay()
    
    def Clear(self, color):
        self.send_command(0x24) # WRITE_RAM
        self.send_data1([color] * self.height * int(self.width / 8))
        self.TurnOnDisplay()
    
    def sleep(self):
        self.send_command(0x10) # DEEP_SLEEP_MODE
        self.send_data(0x01)

    def text_scaled(self, text, x, y, scale=1, color=0):
        """Draw scaled text using the built-in font as a bitmap and expanding pixels.

        This creates a temporary small framebuffer for each input line (8px tall) and scales
        each pixel up by `scale` into the main framebuffer. Works with multiple lines (`\n`).
        """
        if scale <= 1:
            # simple pass-through
            self.image_Landscape.text(text, x, y, color)
            return
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

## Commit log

2025-12-06 USB-C + protection
    [PCB.kicad_sch]
2025-12-06 finishing power, adding in the rp2040
    [PCB.kicad_sch]
2025-12-06 adding the decoupling and grounding
    [PCB.kicad_sch]
2025-12-09 crystal and reset
    [PCB.kicad_sch]
2025-12-09 added the flash
    [PCB.kicad_sch]
2025-12-09 added the FPC connector in
    [PCB.kicad_sch]
2025-12-09 changing the FPC symbol and starting to wire it
    [PCB.kicad_sch]
2025-12-09 more eink wiring
    [PCB.kicad_sch]
2025-12-09 finished wiring the eink connector
    [PCB.kicad_sch]
2025-12-10 wired the eink mosfet logic!
    [PCB.kicad_sch]
2025-12-10 cleaning up the e-ink wiring, fixing BS too!
    [PCB.kicad_sch]
2025-12-10 finished wiring the eink
    [PCB.kicad_sch]
2025-12-10 changed all the global labels to net labels for funesies
    [PCB.kicad_sch]
2025-12-10 chose my NFC RFID IC
    [PCB.kicad_sch]
2025-12-10 wired the NFC RFID IC
    [PCB.kicad_sch]
2025-12-10 wiring NFC RFID to MCU
    [PCB.kicad_sch]
2025-12-10 finished the NFC antenna
    [PCB.kicad_sch]
2025-12-10 assigning all passive footprints
    [PCB.kicad_sch]
2025-12-10 added in the buttons, stole them from @cheyao :D
    [PCB.kicad_sch]
2025-12-10 finished all the footprints, found an inductor
    [PCB.kicad_sch]
2025-12-10 starting the PCB
    [PCB.kicad_pcb]
2025-12-10 grouped all the components together
    [PCB.kicad_pcb]
2025-12-10 cleaned up the schematic and wired MCU pins to get ready for headers
    [PCB.kicad_sch]
2025-12-10 added the header pins in!
    [PCB.kicad_sch]
2025-12-10 finishing touches to the schematic
    [PCB.kicad_sch]
2025-12-10 added in my custom header footprint
    [PCB.kicad_pcb, PCB.kicad_sch]
2025-12-11 getting hte the basic shape in
    [PCB.kicad_pcb]
2025-12-11 fixing the shape
    [PCB.kicad_pcb]
2025-12-11 rounded the corners on the shape!
    [PCB.kicad_pcb]
2025-12-11 starting on some of the decorational elements
    [PCB.kicad_pcb]
2025-12-11 fixing the shape and pin headers
    [PCB.kicad_pcb]
2025-12-11 adding mounting hole
    [PCB.kicad_pcb]
2025-12-11 using a GND plane for soldermask art instead of straight copper
    [PCB.kicad_pcb]
2025-12-11 aligning the USB-C and the EINK
    [PCB.kicad_pcb]
2025-12-11 switching to ablack PCB
    [PCB.kicad_pcb]
2025-12-11 re-wiring a bit for easy routing
    [PCB.kicad_pcb, PCB.kicad_sch]
2025-12-11 re-wiring some more stuff, also laying out some stuff
    [PCB.kicad_pcb, PCB.kicad_sch]
2025-12-11 aligning the caps
    [PCB.kicad_pcb]
2025-12-11 aligning crystal and LDO
    [PCB.kicad_pcb]
2025-12-11 aligning eink stuff
    [PCB.kicad_pcb]
2025-12-11 finished aligning the eink and LED
    [PCB.kicad_pcb]
2025-12-11 aligned the buttons
    [PCB.kicad_pcb]
2025-12-11 adding the tape keepout, re-aligning the LDO and LED
    [PCB.kicad_pcb]
2025-12-11 removed top silkscreen
    [PCB.kicad_pcb]
2025-12-12 added the NFC antenna in
    [PCB.kicad_pcb, PCB.kicad_sch]
2025-12-12 placed the NFC IC and routed it
    [PCB.kicad_pcb]
2025-12-12 working on a new shape
    [PCB.kicad_pcb]
2025-12-12 more decorational shapes
    [PCB.kicad_pcb]
2025-12-12 doing this cool effect on the fill, have to make it work with GND instead though
    [PCB.kicad_pcb]
2025-12-12 re-organizing most of the components
    [PCB.kicad_pcb]
2025-12-12 new NFC antenna
    [PCB.kicad_pcb, PCB.kicad_sch]
2025-12-12 finished with all the NFC stuff
    [PCB.kicad_pcb, PCB.kicad_sch]
2025-12-12 switching to a cooler antenna and easier routing
    [PCB.kicad_pcb]
2025-12-12 heading to school
    [PCB.kicad_pcb]
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2025-12-12 routing flash, and some passives, really dense :D
    [PCB.kicad_pcb]
2025-12-12 wired all the SoC passives and power
    [PCB.kicad_pcb]
2025-12-12 wiring all the pin headers
    [PCB.kicad_pcb]
2025-12-13 re-did routed power and re-did pin headers for easier button routing
    [PCB.kicad_pcb, PCB.kicad_sch]
2025-12-13 routed NFC and a bunch of other stuff
    [PCB.kicad_pcb]
2025-12-13 only a couple more things left to route!
    [PCB.kicad_pcb]
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2025-12-13 proper grounding, and figured out a clean way of doing the antenna no fill
    [PCB.kicad_pcb]
2025-12-13 added asome 3D models, cleaning stuff up a bit
    [PCB.kicad_pcb]
2025-12-13 cleaning up the traces a bit
    [PCB.kicad_pcb]
2025-12-13 a bit more cleaning up!
    [PCB.kicad_pcb]
2025-12-13 fab files, but forgot to run DRC
    [PCB.kicad_pcb, bom.csv, designators.csv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]
2025-12-13 fixed all the DRC errors
    [PCB.kicad_pcb]
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2025-12-13 new fab filess with changes
    [PCB.kicad_pcb]
2025-12-14 actually decided on this inductor!
    [PCB.kicad_pcb, PCB.kicad_sch]
2025-12-14 finishing touches, new fab files!
    [PCB.kicad_pcb, PCB.kicad_sch, bom.csv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]
2025-12-14 more prod files, new BOM and whatnot
    [JLCPCB_BOM.xls]
2025-12-14 moved the buttons, new prod files
    [PCB.kicad_pcb, positions.csv]
2025-12-14 cleaned up the silkscreen and added load cap to antenna
    [PCB.kicad_pcb, PCB.kicad_sch]
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2025-12-14 new BOM, electrically finished, and more polished now :D
    [JLCPCB_BOM.xls]
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2025-12-14 new inductor a bit pissed about it
    [PCB.kicad_pcb, PCB.kicad_sch]
2025-12-14 new fab files, cleaning stuff up too
    [PCB.kicad_sch, bom.csv, positions.csv]
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2026-01-04 adding in the art :D
    [PCB.kicad_pcb]
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2026-01-10 fixing up some of the arti
    [PCB.kicad_pcb]
2026-01-11 adding the front art
    [PCB.kicad_pcb]
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
